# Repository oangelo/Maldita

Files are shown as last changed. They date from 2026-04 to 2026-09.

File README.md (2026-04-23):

# Maldita

Backup de configurações do skate elétrico Maldita.

## Componentes

| Sistema | Componente |
|---|---|
| ESC | Spintend Ubox V2 75V 100A (dual) |
| Motor | Flipsky BLDC 6374 190KV 3250W (x2) |
| Controle Remoto | Spintend Uni1 V2 |
| Bateria | 16S6P, 59.2V nominal, Daly BMS WiFi |
| Rodas | Pneumático 260×85mm (10"×3"), ~50 PSI |
| Transmissão | Corrente 25H, pinhão 9T / coroa 70T (7.78:1) |
| Suspensão | Amortecedor com mola vermelha (a melhorar) |
| Firmware | VESC v6.06 |

## Documentação

- [Controles (ESC + Remoto)](docs/controles.md)
- [Trem de Força (Motor + Transmissão)](docs/trem-de-forca.md)
- [Suspensão](docs/suspensao.md)

## Estrutura

```
Maldita/
├── configs/            # Backups das configurações do VESC Tool
│   ├── motor/
│   ├── app/
│   └── imu/
├── hardware/
│   ├── schematics/
│   ├── pcb/
│   └── mechanical/
│       └── fotos/      # Fotos dos componentes
└── docs/               # Documentação detalhada por subsistema
```

## Licença

A definir.

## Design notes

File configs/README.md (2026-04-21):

# Configurações VESC

Backups exportados do VESC Tool v6.06.

## Pastas

| Pasta | Conteúdo |
|---|---|
| `motor/` | Configuração FOC, detection do motor, parâmetros elétricos |
| `app/` | Configuração do app: PPM, UART, ADC, nRF, etc. |
| `imu/` | Configuração do IMU (se aplicável) |

## Nomenclatura dos Arquivos

- `motor1_<data>.xml` — Config do motor 1
- `motor2_<data>.xml` — Config do motor 2
- `app_<data>.xml` — Config do app
- `full_<data>.xml` — Exportação completa

Formato de data: `YYYY-MM-DD`

## Exportar pelo VESC Tool

1. Conecte via USB
2. **File → Export full configuration** (exporta tudo)
3. Ou exporte seções individuais nas abas de configuração

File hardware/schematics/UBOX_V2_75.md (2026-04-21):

# UBOX_V2_75 — Hardware Specs

## Identificação

- **Nome**: UBOX_V2_75
- **Fabricante**: Spintend
- **Descricao**: Ubox V2 75V 100A x2 J (dual ESC)
- **Placa**: PCB vermelha ("a plaquinha vermelha da Maldita")

## Especificacoes Eletricas

| Parametro | Valor |
|---|---|
| Tensao | 16-75V (pico < 80V) |
| Corrente maxima (por canal) | 100A |
| Corrente dual maxima | 200A total |
| Canais | 2 (dual) |
| Saida 12V | Max 3A (luz + buzina dividem) |
| Saida 5V | Max 500mA |
| Dimensoes | 130 x 83 x 27mm (com parafusos) |
| Peso | 396g |
| Cabo motor | 12AWG 12cm |
| Cabo bateria | 10AWG 12cm |

## Conectores

- (a documentar)

## Componentes Principais

- MCU: (a documentar)
- MOSFETs: (a documentar)
- Driver: (a documentar)

## Controle Remoto

| Parametro | Valor |
|---|---|
| Fabricante | Spintend |
| Modelo | Uni1 V2 |
| Tela | OLED (dados em tempo real) |
| Bateria | Lithium 450mAh |
| Duracao | ~11 horas |
| Frequencia | 2.4GHz |
| Protocolo | PPM ou UART (configuravel) |
| CanBus | On/Off pelo controle |
| Botao extra | Controle de luz de freio / farol / buzina |
| Porta IO | Para buzina e luz |
| Firmware | Bootloader, suporte a atualizacao online |
| Compatibilidade | VESC, Spintend Ubox V2 |
| Receptor | Integrado na UBox V2 (ou receptor unico separado) |

## Motores

### Specs Gerais

| Parametro | Valor |
|---|---|
| Modelo | Flipsky BLDC 6374 190KV 3250W |
| Quantidade | 2 (dual, um por canal) |
| Tipo | Brushless DC (BLDC) |
| KV | 190KV |
| Potencia maxima | 3250W cada |
| Corrente maxima | 85A |
| Tensao maxima | 12S (50.4V) |
| Torque maximo | 8Nm |
| Resistencia | 0.05 Ohm |
| Protecao | A prova d'agua e a prova de poeira |

### Eletrico / Magnetico

| Parametro | Valor |
|---|---|
| Numero de polos | 14 (7 pares de polos) |
| Ima | N42SH (alta temperatura) |
| Estator | Aco japones laminado, 0.2mm de espessura |
| Sensores | Hall Effect 120 graus, fio sensor JST-ZH 6pin 1.5mm pitch |
| Modo | Sensorless (comum) ou com sensores Hall |

### Dimensoes e Mecanico

| Parametro | Valor |
|---|---|
| Diametro | 63mm |
| Comprimento | 74mm |
| Eixo | 8mm diametro, 32mm comprimento |
| Chaveta | 3x3x20mm (chave incluida) |
| Peso | 0.86kg / 1.9 lb |
| Parafusos montagem | M4 (nao incluidos) |

### Fiacao

| Cor | Fase |
|---|---|
| Azul | A |
| Preto | B |
| Amarelo | C |

- Fios: silicone 12AWG, 130mm, conector bullet 4.0mm (macho)

## Bateria

| Parametro | Valor |
|---|---|
| Configuracao | 16S6P |
| Tensao nominal | 59.2V (16 x 3.7V) |
| Tensao carga cheia | 67.2V (16 x 4.2V) |
| BMS | Daly Smart BMS com modulo WiFi |
| Celulas | Antigas (< 2500mAh por celula) |
| Capacidade estimada | < 15Ah (6 x < 2500mAh) |

## Rodas

| Parametro | Valor |
|---|---|
| Designacao | 3.00-4 / 10"x3" / 260x85 |
| Diametro externo | 260mm |
| Largura | 85mm |
| Tipo | Pneumatico com camara de ar |
| Pressao | ~50 PSI |
| Aro | 4" (~102mm) |

## Transmissao

| Parametro | Valor |
|---|---|
| Tipo | Corrente (chain drive) |
| Pinhao do motor | 04C, 9T, furo 8mm |
| Material pinhao | Aco 45#, tratamento superficial de tempra por alta frequencia |
| Passo pinhao | 6.35mm |
| Espessura dente pinhao | 3mm |
| Coroa da roda | 25H, 70T, 29mm |
| Relacao de marcha | 7.78:1 (70/9) |
| Relacao original | 5.22:1 (47/9) — coroa trocada por mais torque |

## Velocidade Maxima Teorica

```
Bateria 16S:
  Nominal:      59.2V
  Carga cheia:  67.2V

Motor 190KV:
  RPM nominal:     190 x 59.2 = 11.248 RPM
  RPM carga cheia: 190 x 67.2 = 12.768 RPM

Relacao de marcha: 7.78:1 (70T / 9T)
  RPM roda nominal:     11.248 / 7.78 = 1.446 RPM
  RPM roda carga cheia: 12.768 / 7.78 = 1.641 RPM

Roda 260mm:
  Circunferencia: pi x 0.260m = 0.817m
```

| Condicao | Velocidade |
|---|---|
| Nominal (59.2V) | 70.9 km/h |
| Carga cheia (67.2V) | 80.4 km/h |
| Estimada na pratica (~80%) | 57-64 km/h |

## Notas

- Placa de cor vermelha, projeto da Spintend/Maldita.
- Compativel com firmware VESC v6.06.
- Cada canal (motor 1 e motor 2) deve ser configurado individualmente no VESC Tool.
- Receptor do controle Uni1 V2 integrado na UBox V2 quando comprado junto.

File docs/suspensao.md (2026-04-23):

# Suspensão

## Amortecedor

- **Mola — diâmetro do arame (d)**: 4.5mm
- **Mola — folga entre espiras**: 3.5mm (passo = 8mm)
- **Mola — diâmetro externo (De)**: 30.7mm
- **Mola — comprimento livre (L0)**: 57.5mm
- **Borracha central**: bola de borracha no meio do amortecedor com curso de ~35mm

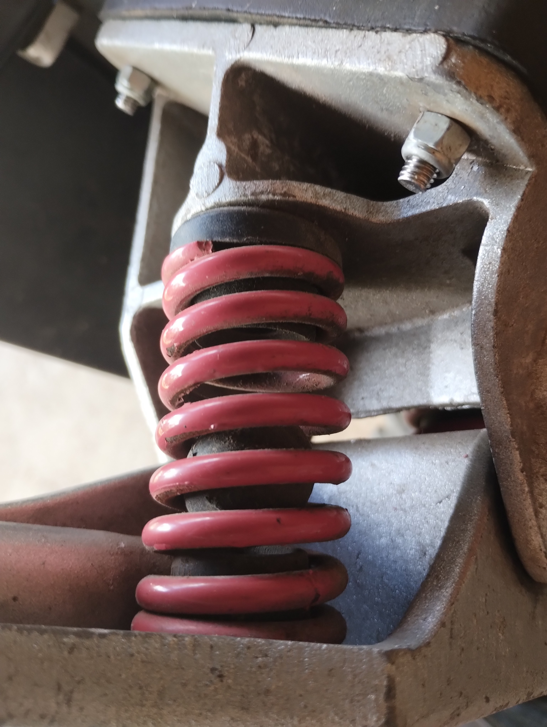
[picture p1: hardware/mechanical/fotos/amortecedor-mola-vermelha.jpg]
Amortecedor — mola vermelha


## Problema identificado

Em terreno com muitas pedras, o skate vibra excessivamente em alta frequência. O pré-load da mola está adequado (boa estabilidade em curvas), então o problema não é rigidez da mola, mas falta de amortecimento para vibrações de alta frequência.

## Solução planejada — batente TPU impresso

A borracha é solta dentro da mola — só entra em contato quando a suspensão atinge o fim do curso (bump stop). A borracha cumpre bem seu papel de batente, mas nunca foi projetada para absorver vibrações de alta frequência.

Substituir por um batente impresso em TPU, com vantagens sobre a borracha original:

1. **Absorção progressiva de fim de curso** — geometria vazada (gyroid, favo de mel) comprime progressivamente: mole no início do contato, endurece conforme comprime, evitando impacto abrupto metal a metal
2. **Amortecimento de alta frequência** — TPU dissipa energia por histerese do material, reduzindo vibração transmitida ao piloto
3. **Ajuste por infill%** — sem trocar filamento, só ajustando a densidade de impressão

### Considerações de design

- **Material**: TPU flexível, Shore A 85–95
- **Geometria**: estrutura interna vazada (gyroid recomendado para compressão progressiva)
- **Dimensões**: deve caber no curso de ~35mm da borracha original
- **Iteração**: imprimir variações de infill% e testar em campo

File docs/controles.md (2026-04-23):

# Controles

## ESC — Spintend Ubox V2 75V 100A

- **Modelo**: UBOX_V2_75 (x2 J — dual)
- **Topologia**: Dual ESC (dois canais independentes)
- **Tensão**: 16–75V (pico < 80V)
- **Corrente máxima**: 100A por canal / 200A total
- **Dimensões**: 130 × 83 × 27mm / 396g
- **Saída 12V**: máx 3A (luz + buzina)
- **Saída 5V**: máx 500mA
- **Firmware**: v6.06 (base VESC)

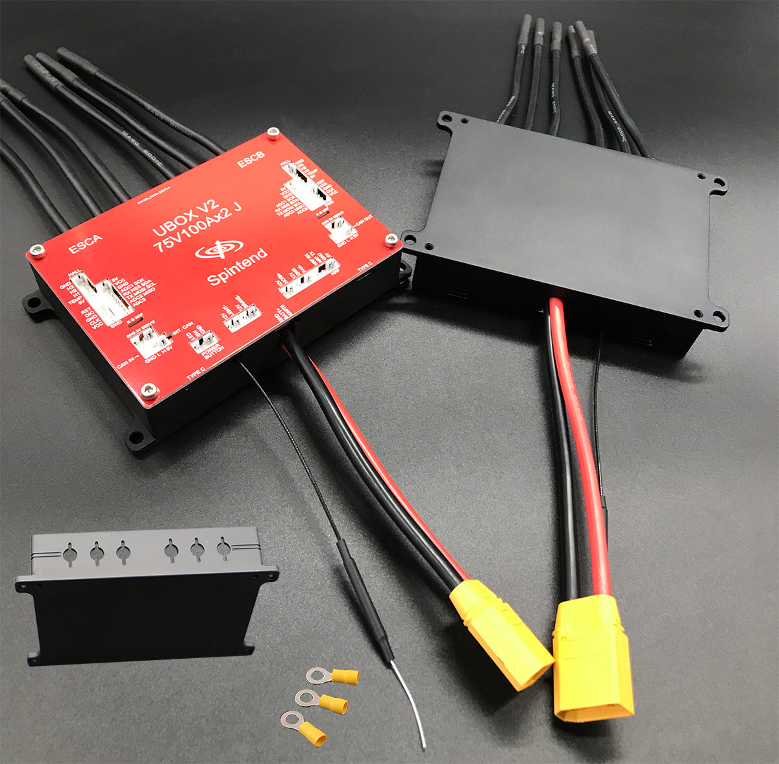
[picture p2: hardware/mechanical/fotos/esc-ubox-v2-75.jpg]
ESC Ubox V2 75


## Controle Remoto — Spintend Uni1 V2

- **Tela**: OLED (dados em tempo real)
- **Bateria**: Lithium 450mAh (~11h de duração)
- **Frequência**: 2.4GHz
- **Protocolo**: PPM ou UART (configurável)
- **CanBus**: On/Off pelo controle
- **Botão extra**: luz de freio / farol / buzina
- **Firmware**: Bootloader, suporte a atualização online

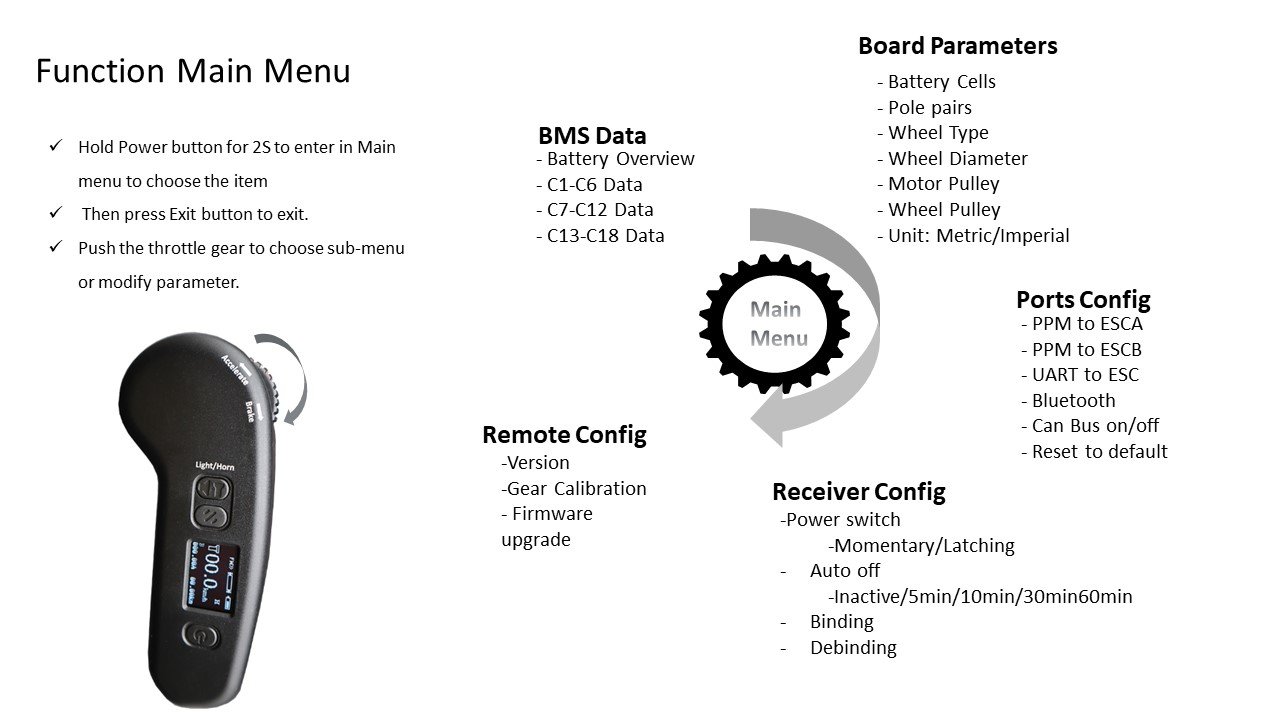
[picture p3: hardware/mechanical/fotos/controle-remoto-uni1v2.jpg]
Controle Remoto Uni1 V2


## Exportar Configurações (VESC Tool v6.06)

1. Conecte o ESC via USB
2. Vá em **File → Export full configuration**
3. Salve o XML em `configs/`
4. Para dual: exporte motor 1 e motor 2 separadamente

## Restaurar Configurações

1. Conecte o ESC via USB
2. Vá em **File → Import full configuration**
3. Selecione o arquivo XML
4. Apply e escreva na flash

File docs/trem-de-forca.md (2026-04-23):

# Trem de Força

## Motor — Flipsky BLDC 6374 190KV

- **Tipo**: Brushless DC (BLDC), sensorless / Hall
- **KV**: 190KV
- **Potência**: 3250W cada (x2)
- **Corrente máx**: 85A
- **Tensão máx**: 12S (50.4V)
- **Torque máx**: 8Nm
- **Resistência**: 0.05 Ohm
- **Polos**: 14 (7 pares)
- **Ímãs**: N42SH
- **Eixo**: 8mm x 32mm, chaveta 3x3x20mm
- **Peso**: 0.86kg cada
- **Dimensões**: 63mm x 74mm
- **Proteção**: À prova d'água e à prova de poeira

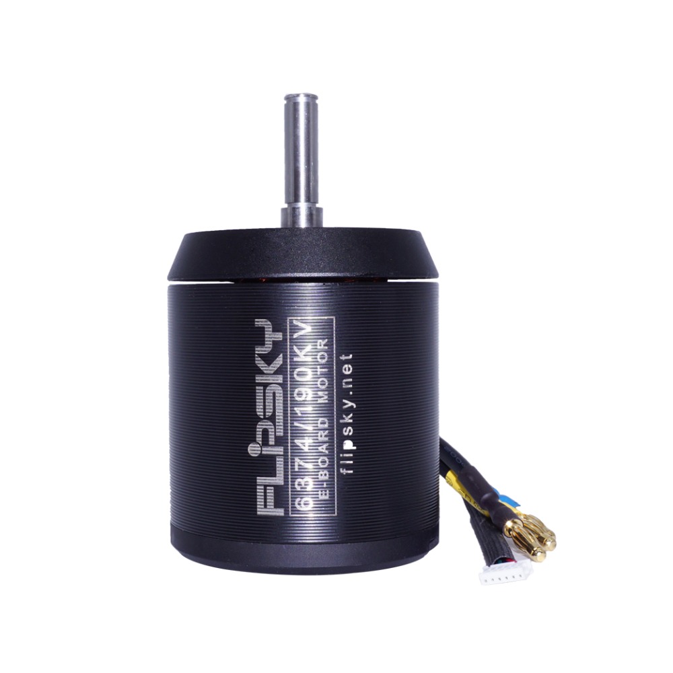
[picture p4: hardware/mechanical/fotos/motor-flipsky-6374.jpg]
Motor Flipsky 6374


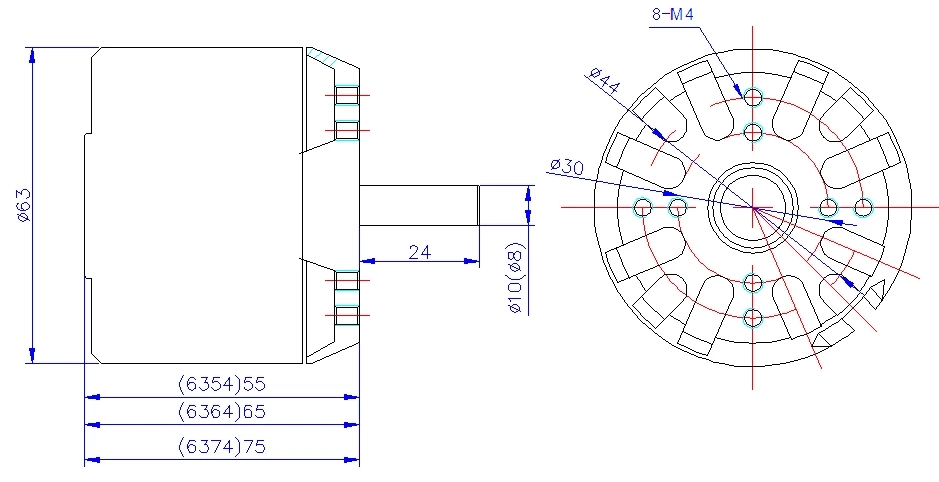
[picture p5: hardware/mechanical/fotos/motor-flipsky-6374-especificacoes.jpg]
Especificações Motor Flipsky 6374


## Transmissão — Chain Drive

- **Tipo**: Corrente (chain drive)
- **Pinhão do motor**: 04C, 9T, furo 8mm, aço 45#
- **Coroa da roda**: 25H, 70T, 29mm (original: 47T — trocada por mais torque)
- **Relação de marcha**: 7.78:1

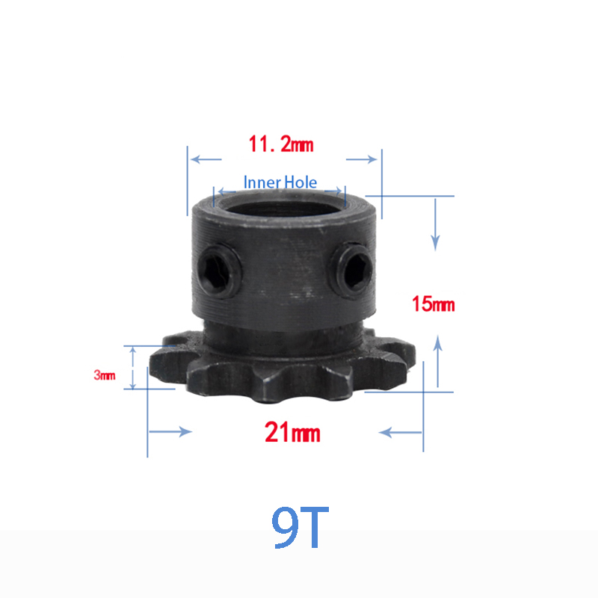
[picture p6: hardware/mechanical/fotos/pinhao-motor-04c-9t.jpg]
Pinhão motor 04C 9T


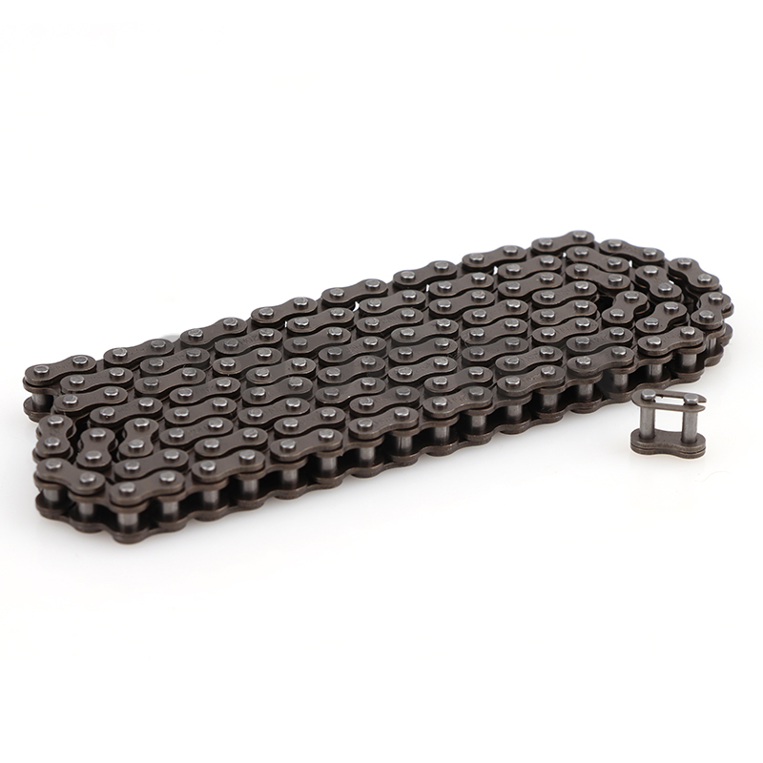
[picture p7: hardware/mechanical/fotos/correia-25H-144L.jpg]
Correia 25H 144L


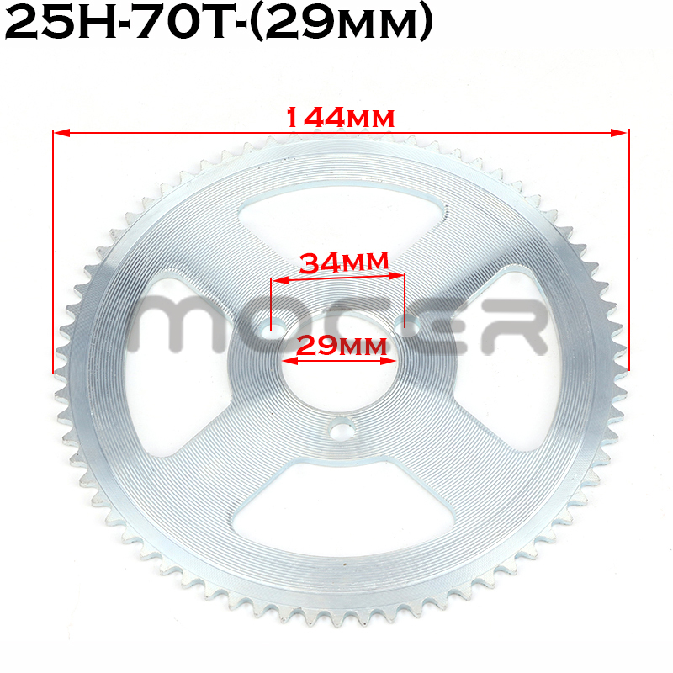
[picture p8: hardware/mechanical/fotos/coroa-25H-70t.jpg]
Coroa 25H 70T


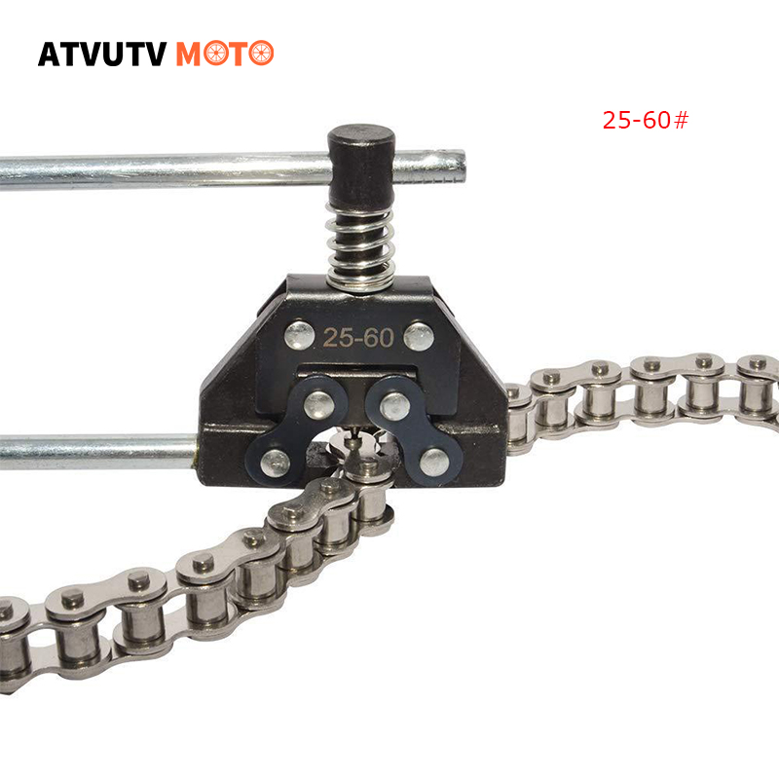
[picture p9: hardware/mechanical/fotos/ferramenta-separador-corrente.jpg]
Ferramenta separador de corrente


## Velocidade Máxima Teórica

| Condição | Velocidade |
|---|---|
| Nominal (59.2V) | 70.9 km/h |
| Carga cheia (67.2V) | 80.4 km/h |
| Estimada na prática (~80%) | 57–64 km/h |

> Cálculo: 190KV × 59.2V = 11.248 RPM → ÷ 7.78 = 1.446 RPM roda → × π × 0.260m = 70.9 km/h

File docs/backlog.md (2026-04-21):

# Maldita — Backlog de Otimizações

Estado atual: `Sensor Mode = Hall Sensors`, HFI descartado (ver sessão 2026-04-21).

---

## Pra qualidade de FOC
- [ ] `Sensor Mode` → `Hall Sensors`
- [ ] Refazer detecção específica dos Halls (`hall_analyze` ou wizard)
- [ ] `FOC → Advanced → Current Sample Mode` → `V0 and V7 Interpolation` (ou `V0 only` se Ubox não suportar phase shunts)
- [ ] `FOC → Advanced → MTPA Mode` → `IQ Target` (aproveita saliência pra torque/A)
- [ ] `FOC → Advanced → Current Decoupling Mode` → `BEMF`
- [ ] `FOC → Hall Sensors → FOC Hall Extra Samples` → 3 ou 4

## Pra dual VESC via CAN
- [ ] VESC mestre: `Controller ID = 0`
- [ ] VESC escravo: `Controller ID = 1`
- [ ] `Send CAN Status` → `Enabled (1, 2, 3, 4, 5)` em ambos
- [ ] Mestre: `Multiple ESCs over CAN` → `Enabled`
- [ ] Escravo: `App to Use` → `None` ou `No App`

## Pra segurança e comportamento
- [ ] `Wattage Max` → valor realista (ex: 3000W)
- [ ] `Soft RPM Limit Start/End` → 70000/80000 ERPM (consistente com velocidade alvo)
- [ ] Configurar sensor de temperatura de motor (se houver NTC interno)

## Pra App Config (throttle)
- [ ] `Control Type` → `Current No Reverse Brake Button`
- [ ] `Positive Ramping Time` → 0.4s
- [ ] `Negative Ramping Time` → 0.2s
- [ ] `Current Boost at Start` → ativar (pico extra na arrancada)
- [ ] `Input Deadband` → 15%

## Problemas abertos
- [ ] Roda presa não faz força enquanto a outra gira (investigar dual VESC via CAN)
- [ ] Diferença de resistência entre motores (13.87 vs 17.48 mΩ) — investigar cabeamento motor 116

## Soluções alternativas (se Hall não for suficiente)
- [ ] Encoder magnético absoluto no eixo (AS5047P, MT6701) via VESC Express
- [ ] Redução mecânica maior (70T → 85T ou 90T) pra multiplicar torque nas rodas

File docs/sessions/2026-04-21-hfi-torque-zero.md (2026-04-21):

# Maldita — Debug de torque em velocidade zero (sessão de HFI)

**Data:** 2026-04-21

## Objetivo
Resolver a falta de torque dos motores em velocidade zero (arrancada em rampa/lombada parada).

## Hardware
- 2x Flipsky BLDC 6374 190KV (saliência alta, mas SPM)
- 1x Spintend Ubox V2 75V 100Ax2 J (dual VESC, CAN-bus)
- 16S6P, ~59.2V nominal
- Controle Spintend Uni1 V2
- Firmware VESC v6.06

## Parâmetros detectados (FOC Detection Wizard)

| Parâmetro | VESC 58 | VESC 116 |
|---|---|---|
| Motor R | 13.87 mΩ | 17.48 mΩ |
| Motor L | 19.71 µH | 20.42 µH |
| Motor Lq-Ld | 7.45 µH | 8.04 µH |
| Flux Linkage | 4.42 mWb | 4.43 mWb |
| Sensors | Hall | Hall |

**Observações:** Flux linkage consistente entre motores. Saliência de ~38% parecia boa pra HFI na teoria. Diferença de 26% na resistência entre motores merece investigação (cabeamento ou conexões).

## O que tentamos

### 1. Ativação do HFI
- `Sensor Mode`: testado `HFI`, `45 Deg V0V7 HFI (Silent)`, `VSS`
- Nota: descobri que no VESC atual não existe "HFI + Hall Sensors" combinado como eu tinha sugerido inicialmente. HFI funciona puro, com fallback pro observer BEMF acima de `Sensorless ERPM HFI`
- HFI só fica ativo quando há comando de corrente. Em idle puro sem throttle, não injeta

### 2. Ajustes de voltages do HFI (várias iterações)

| Parâmetro | Default | Tentativas | Observação |
|---|---|---|---|
| HFI Start Voltage | 20V | 8V → 15V → 20V | Aumentar não melhorou |
| HFI Run Voltage | 4V | 4V → 8V → 15V | |
| HFI Max Voltage | 6V | 6V → 15V → 25V | |
| HFI Gain | 0.3 | 0.1 → 0.3 → 1.0 | |
| Sensorless ERPM HFI | 3000 | 3000 → 10000 | |
| Ambiguity Resolve Current | 60A | 60A → 40A | Menos tranco na partida |

### 3. Diagnóstico via RT Data → Rotor Position

**Capturas feitas:** Observer com motor sob rotor_lock_openloop 1A, 3A, 5A

**Resultado:** Observer oscila ±20-30° em vez de ficar estável. Em movimento, acompanha mas com erro angular significativo. Conclusão: HFI estima posição com qualidade insuficiente pra gerar torque confiável em zero.

### 4. Comandos de terminal úteis descobertos
- `rotor_lock_openloop <current> <time> <angle>` — trava rotor pra teste
- `foc_openloop <current> <erpm>` — rotação em malha aberta
- `foc_plot_hfi_en 1` — habilita debug plot de HFI
- `faults` / `faults_reset` — gerenciamento de falhas

## Conclusão sobre HFI
**HFI não é viável nesse motor específico.** Saliência medida (7.45 µH) parece boa no papel mas provavelmente é saliência de saturação, não magnética real. Típico de outrunner SPM como o 6374. Aumentar voltages piorou a estimativa (saturação suprime saliência residual).

## Decisão
Voltar pra `Sensor Mode = Hall Sensors` e compensar com otimizações de FOC.

## Problemas identificados além do torque em zero

**Roda presa não faz força enquanto a outra gira:** pode ser configuração de dual VESC via CAN (não HFI). Investigar após aplicar otimizações.

**Diferença de resistência entre motores (13.87 vs 17.48 mΩ):** investigar conexões/cabeamento do motor 116.

## Testes que validaram/invalidaram hipóteses

| Teste | Resultado |
|---|---|
| HFI som em idle | Só chia com comando de corrente ativo (normal) |
| Transição HFI→observer | Funciona: chia parado, silencia acelerando, volta a chiar ao desacelerar |
| Observer com roda manual | Sem comando, observer desliga (teste inválido) |
| Observer com rotor_lock | Oscilações grandes, HFI instável |
| Aumento de voltage | Piorou (saturação, contraintuitivo) |
| Saliência efetiva | Insuficiente pra HFI confiável |

## Solução alternativa se Hall não for bom o suficiente
- Encoder magnético absoluto no eixo (AS5047P, MT6701) via VESC Express
- Redução mecânica maior (70T → 85T ou 90T) pra multiplicar torque nas rodas
- Ambas as soluções evitam a limitação elétrica do HFI em motores SPM

---

**Próxima sessão:** aplicar as otimizações do backlog, testar dual VESC via CAN, validar arrancada em lombada real.

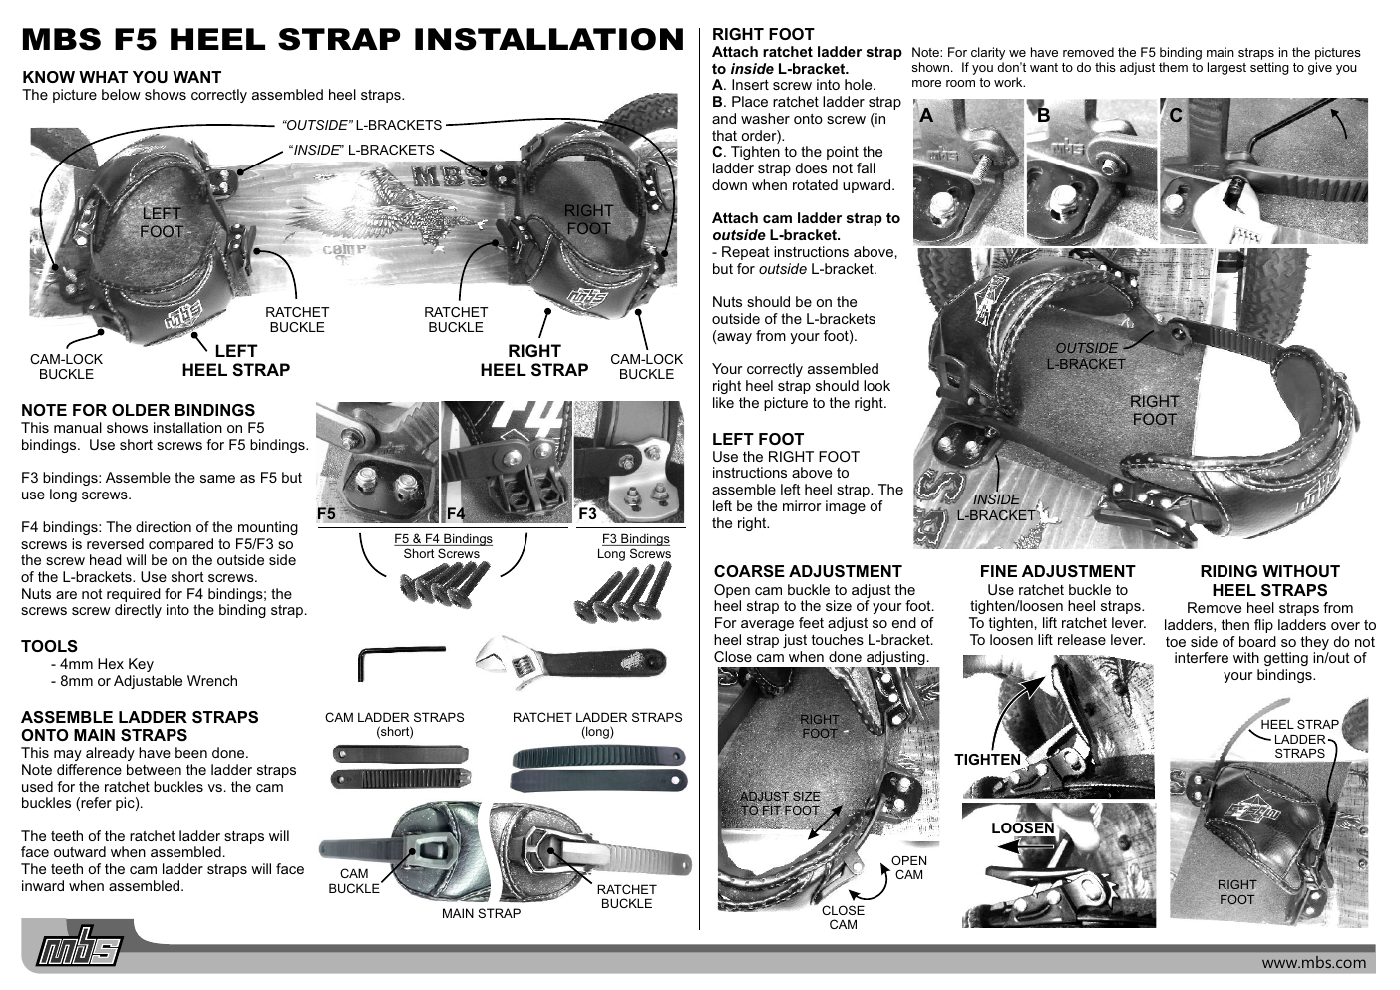
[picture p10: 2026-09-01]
hardware/mechanical/fotos/heel-strap-mbs-f5-referencia.png

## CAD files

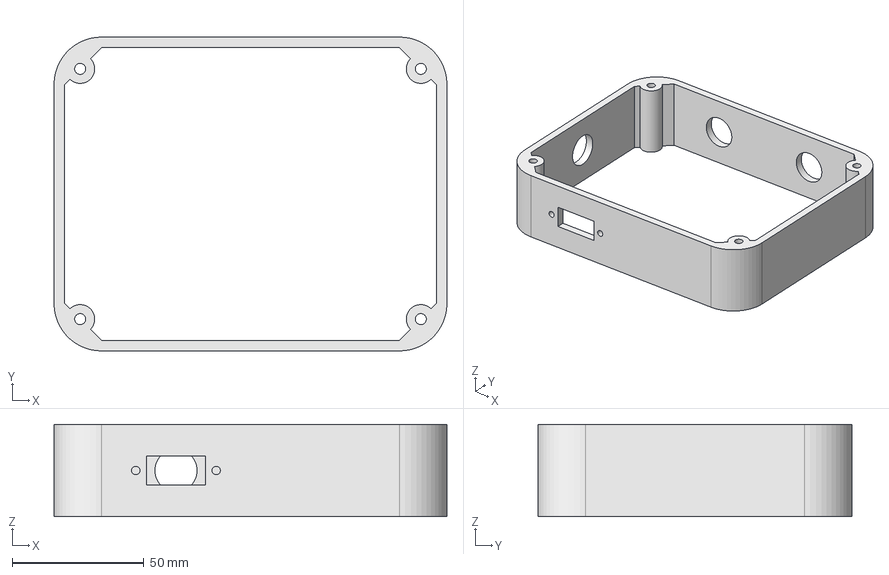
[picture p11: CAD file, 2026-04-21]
hardware/mechanical/ubox v2 ax2j box_base.FCStd
149.0 x 119.0 x 35.0 mm

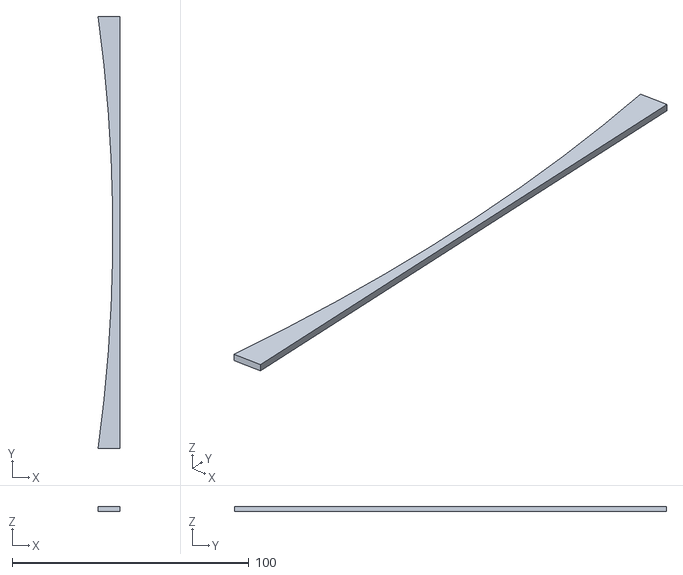
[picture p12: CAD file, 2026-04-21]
hardware/mechanical/curvatura skate.STL
9.28 x 182.6 x 2.00

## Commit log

2026-04-21 init: repositório Maldita - backup de configs VESC v6.06 (UBOX_V2_75, Flipsky 6374 190KV x2)
2026-04-21 docs: adiciona controle remoto Uni1 v2 2.4GHz compatível VESC
2026-04-21 docs: transmissão chain drive — pinhão 04C 9T, coroa 25H 70T (relação 7.78:1)
2026-04-21 docs: specs completas do motor Flipsky 6374 190KV — 14 polos, 0.05 Ohm, Hall sensors
2026-04-21 docs: bateria 16S6P (Daly BMS WiFi), rodas 260x85, controle Uni1 V2 completo, specs UBox V2, velocidade teorica ~71-80 km/h
2026-04-21 docs: sessão de debug HFI + backlog de otimizações FOC/dual CAN
2026-04-21 Adicionando desenhos da caixa do vesc, versão antiga, não sei se tenho as atualizadas
    [curvatura skate.STL, ubox v2 ax2j box_base.FCStd]
2026-04-23 docs: specs e foto do amortecedor (mola vermelha) — a melhorar
2026-04-23 docs: reorganiza documentação em controles, trem-de-forca e suspensao
    README enxuto com tabela resumo e links. Imagens renomeadas e movidas
    para hardware/mechanical/fotos/.
2026-04-23 docs: suspensão — diagnóstico de vibração e plano de batente TPU
2026-08-23 backup: lista de tasks do Google (Maldita) antes da migração para issues
2026-09-01 docs: referência de instalação de heel strap (MBS F5) para adaptação DIY
